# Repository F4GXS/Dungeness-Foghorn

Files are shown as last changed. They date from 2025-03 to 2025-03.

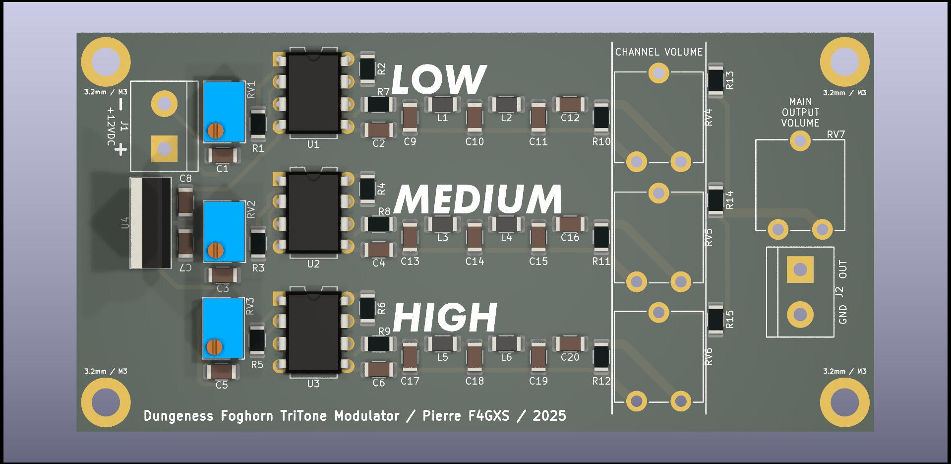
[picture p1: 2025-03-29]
FogHorn_PCB_1.jpg

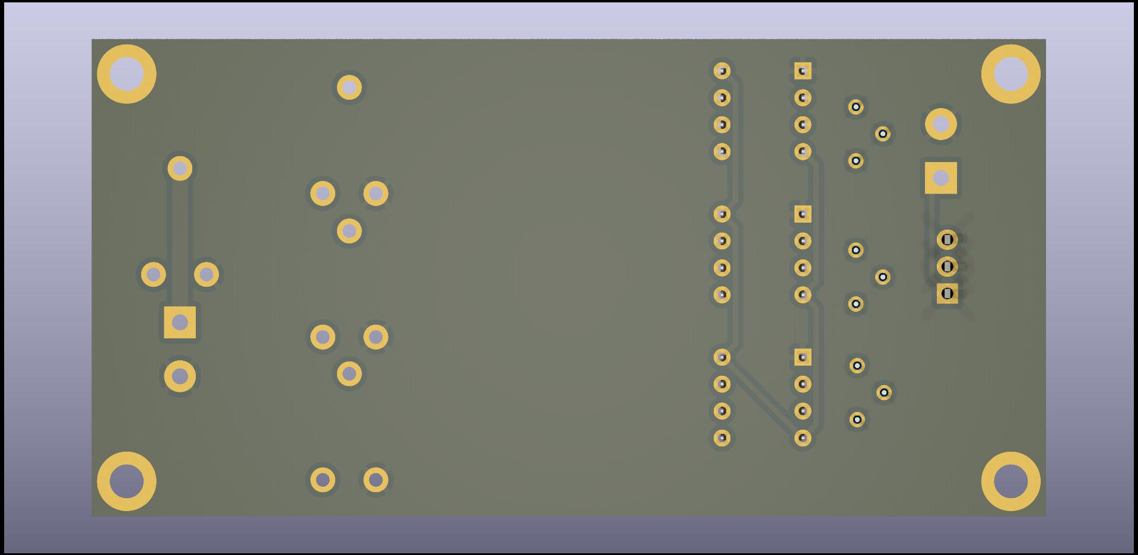
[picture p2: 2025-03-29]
FogHorn_PCB_2.jpg

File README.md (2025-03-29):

# Dungeness Lighthouse / St Ann's Lighthouse Foghorn Modulator
Tritone modulation of the famous Foghorn from the Dungeness Lighthouse #5 and the St Ann's Lighthouse.

The "Foghorn TriTone Modulator" is a very simple project I made to remind us of the famous and very specific tone of the foghorn.

mqdefault (https://www.youtube.com/watch?v=U48cCQ7XAnM)  
Click this image to hear the sound.  
_Source : YouTube -  St Anns Fog Signal / "Association of Lighthouse Keepers" Channel_

Dungeness_Lighthouse5
Dungeness_Lighthouse5_FogHornSPK (https://www.youtube.com/watch?v=Ncq_DsAXrBo)  
Click this image to hear the sound.  
_Source : YouTube -  Dungeness 5 fog horn: 26 minutes of Tannoy fog horn / "hellooldchap" Channel_

> In 1954-56, trials had been carried out at Dungeness of a triple-frequency electric fog signal, sounded through tannoy emitters built into a curved stack of precast concrete blocks. The experiment was deemed a success, and tannoy stacks were subsequently installed by Trinity House at around a dozen lighthouse stations. At Dungeness itself, a stack of sixty such emitters was incorporated into the design of the lighthouse tower itself; these remained in use until the year 2000, when they were replaced by an electronic signal installed at the base of the tower. It sounded three blasts every minute (altered in 2022 to one blast every 30 seconds).  
_Source : [Wikipedia](https://en.wikipedia.org/wiki/Dungeness_Lighthouse)_

## Electronic Schematic

FogHorn_Schema

This modulator is very simple, bases on 3 NE555 Timer IC for each tone, the NE555 can easily create square wave tone with few component for tuning and each NE555 have a 5 Order LowPass Filter to transform squares waveforms tones into sines waveforms tone.

The power input voltage are 12VDC equiped with a LM7805 5VDC for the NE555.

Each channel have a multiturn potentiometer for precision frequency tuning.

The modulator are equiped with a passive inboard mixer, 3 potentiometer (1 pot for each channel, regulate the volume of each tone) and 1 for the main volume to regulate the main mix.

## Printed Circuit Board

FogHorn_PCB_1

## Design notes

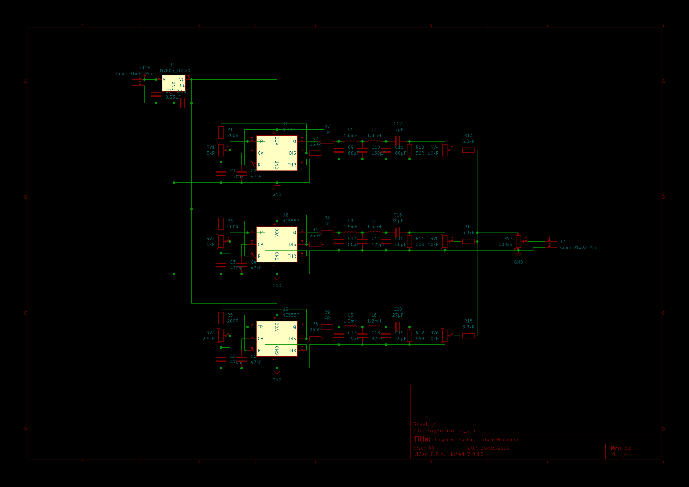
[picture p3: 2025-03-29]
FogHorn_Schema.jpg

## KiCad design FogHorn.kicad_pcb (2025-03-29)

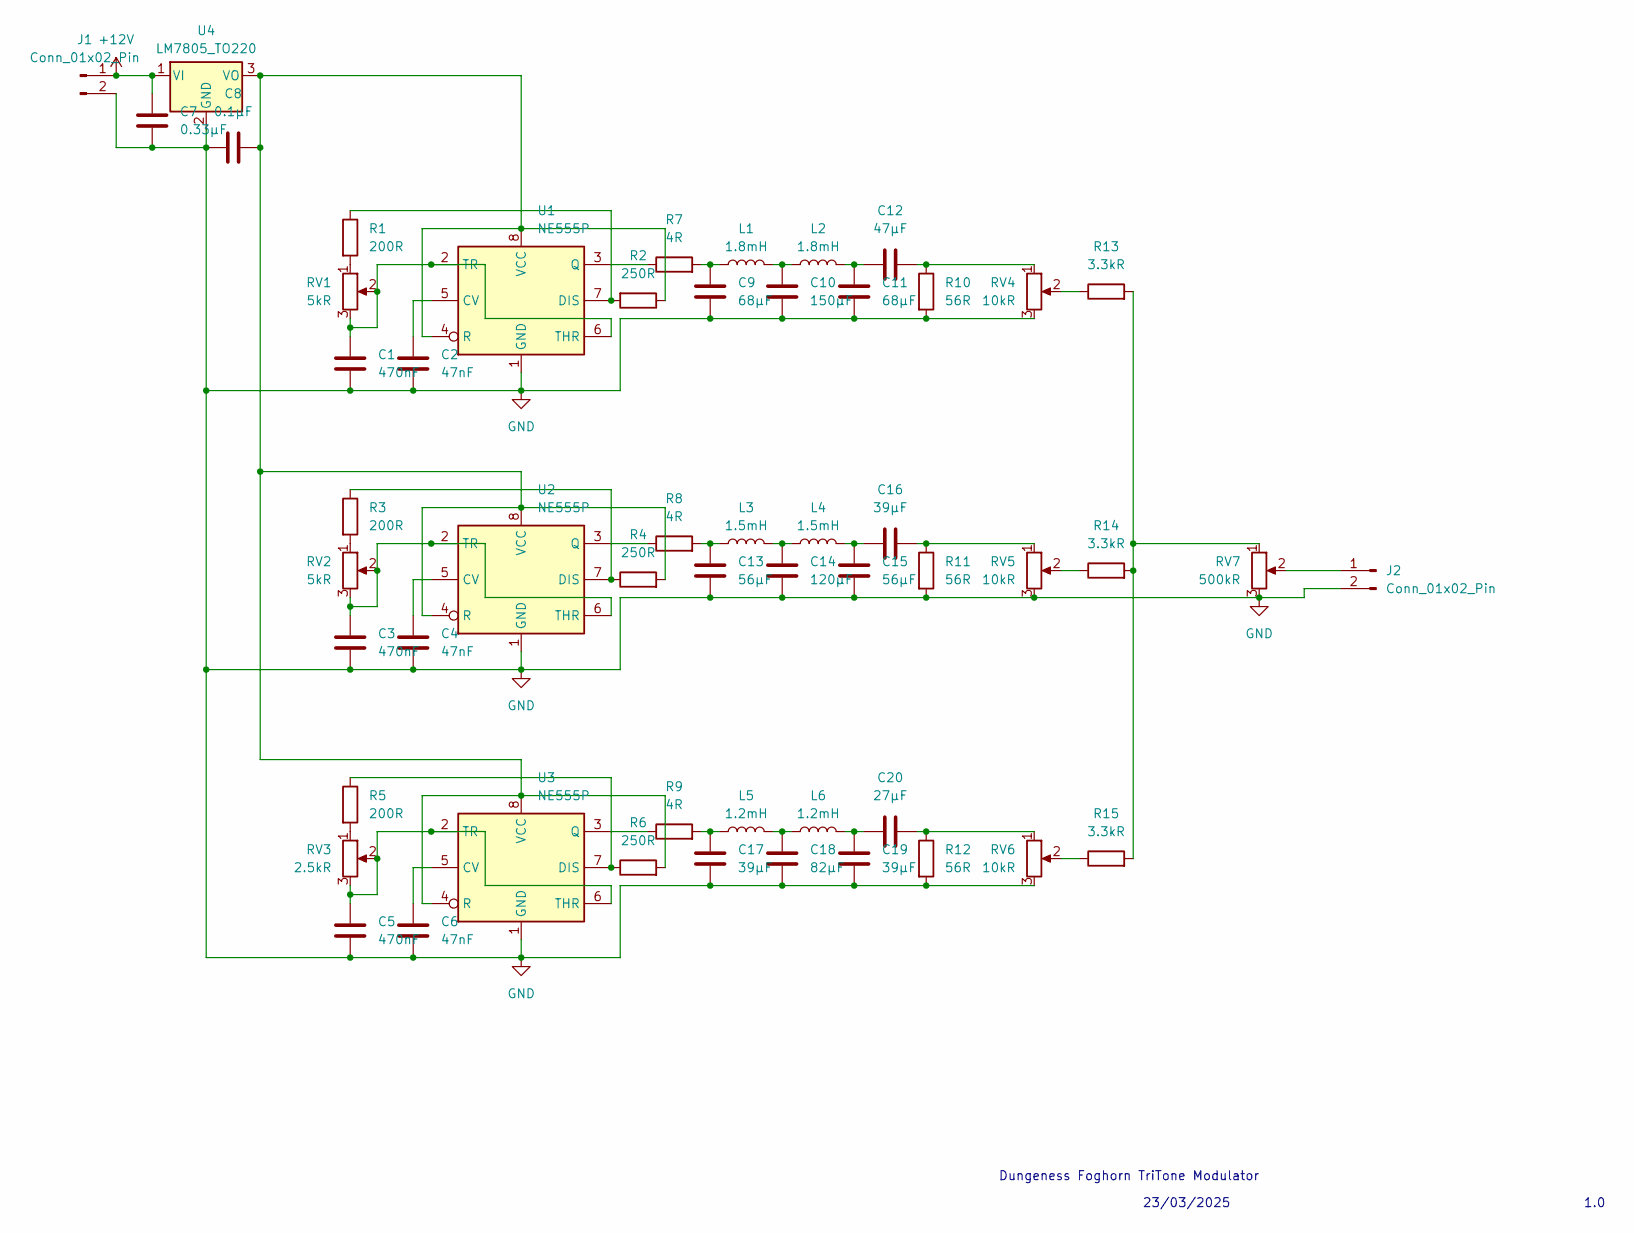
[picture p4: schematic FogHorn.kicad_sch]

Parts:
C1, C3, C5: 470nF; C_1206_3216Metric
C2, C4, C6: 47nF; C_1206_3216Metric
C7: 0.33µF; C_1206_3216Metric
C8: 0.1µF; C_1206_3216Metric
C9, C11: 68µF; C_1206_3216Metric
C10: 150µF; C_1206_3216Metric
C12: 47µF; C_1206_3216Metric
C13, C15: 56µF; C_1206_3216Metric
C14: 120µF; C_1206_3216Metric
C16, C17, C19: 39µF; C_1206_3216Metric
C18: 82µF; C_1206_3216Metric
C20: 27µF; C_1206_3216Metric
J1, J2: Conn_01x02_Pin; TerminalBlock_bornier-2_P5.08mm
L1, L2: 1.8mH; L_1206_3216Metric
L3, L4: 1.5mH; L_1206_3216Metric
L5, L6: 1.2mH; L_1206_3216Metric
R1, R3, R5: 200R; R_1206_3216Metric
R2, R4, R6: 250R; R_1206_3216Metric
R7, R8, R9: 4R; R_1206_3216Metric
R10, R11, R12: 56R; R_1206_3216Metric
R13, R14, R15: 3.3kR; R_1206_3216Metric
RV1, RV2: 5kR; Potentiometer_Bourns_3266W_Vertical
RV3: 2.5kR; Potentiometer_Bourns_3266W_Vertical
RV4, RV5, RV6: 10kR; Potentiometer_ACP_CA9-V10_Vertical
RV7: 500kR; Potentiometer_ACP_CA9-V10_Vertical
U1, U2, U3: NE555P; DIP-8_W7.62mm
U4: LM7805_TO220; TO-220-3_Vertical

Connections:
+12V: C7.1, J1.1, U4.1 (VI)
GND: C1.2, C2.2, C3.2, C4.2, C5.2, C6.2, C7.2, C8.1, C9.2, C10.2, C11.2, C13.2, C14.2, C15.2, C17.2, C18.2, C19.2, J1.2, J2.2, R10.2, R11.2, R12.2, RV4.3, RV5.3, RV6.3, RV7.3, U1.1 (GND), U2.1 (GND), U3.1 (GND), U4.2 (GND)
unnamed: C9.1, L1.1, R7.2
unnamed: C10.1, L1.2, L2.1
unnamed: C11.1, C12.1, L2.2
unnamed: C12.2, R10.1, RV4.1
unnamed: C13.1, L3.1, R8.2
unnamed: C14.1, L3.2, L4.1
unnamed: C15.1, C16.1, L4.2
unnamed: C16.2, R11.1, RV5.1
unnamed: C17.1, L5.1, R9.2
unnamed: C18.1, L5.2, L6.1
unnamed: C19.1, C20.1, L6.2
unnamed: C20.2, R12.1, RV6.1
unnamed: J2.1, RV7.2
unnamed: R1.2, RV1.1
unnamed: R3.2, RV2.1
unnamed: R5.2, RV3.1
unnamed: R13.1, RV4.2
unnamed: R13.2, R14.2, R15.2, RV7.1
unnamed: R14.1, RV5.2
unnamed: R15.1, RV6.2
unnamed: C2.1, U1.5 (CV)
unnamed: R1.1, R2.2, U1.7 (DIS)
unnamed: R7.1, U1.3 (Q)
unnamed: C8.2, R2.1, R4.2, R6.2, U1.4 (R), U1.8 (VCC), U2.4 (R), U2.8 (VCC), U3.4 (R), U3.8 (VCC), U4.3 (VO)
unnamed: C1.1, RV1.2, RV1.3, U1.2 (TR), U1.6 (THR)
unnamed: C4.1, U2.5 (CV)
unnamed: R3.1, R4.1, U2.7 (DIS)
unnamed: R8.1, U2.3 (Q)
unnamed: C3.1, RV2.2, RV2.3, U2.2 (TR), U2.6 (THR)
unnamed: C6.1, U3.5 (CV)
unnamed: R5.1, R6.1, U3.7 (DIS)
unnamed: R9.1, U3.3 (Q)
unnamed: C5.1, RV3.2, RV3.3, U3.2 (TR), U3.6 (THR)

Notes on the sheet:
Dungeness Foghorn TriTone Modulator
1.0
23/03/2025

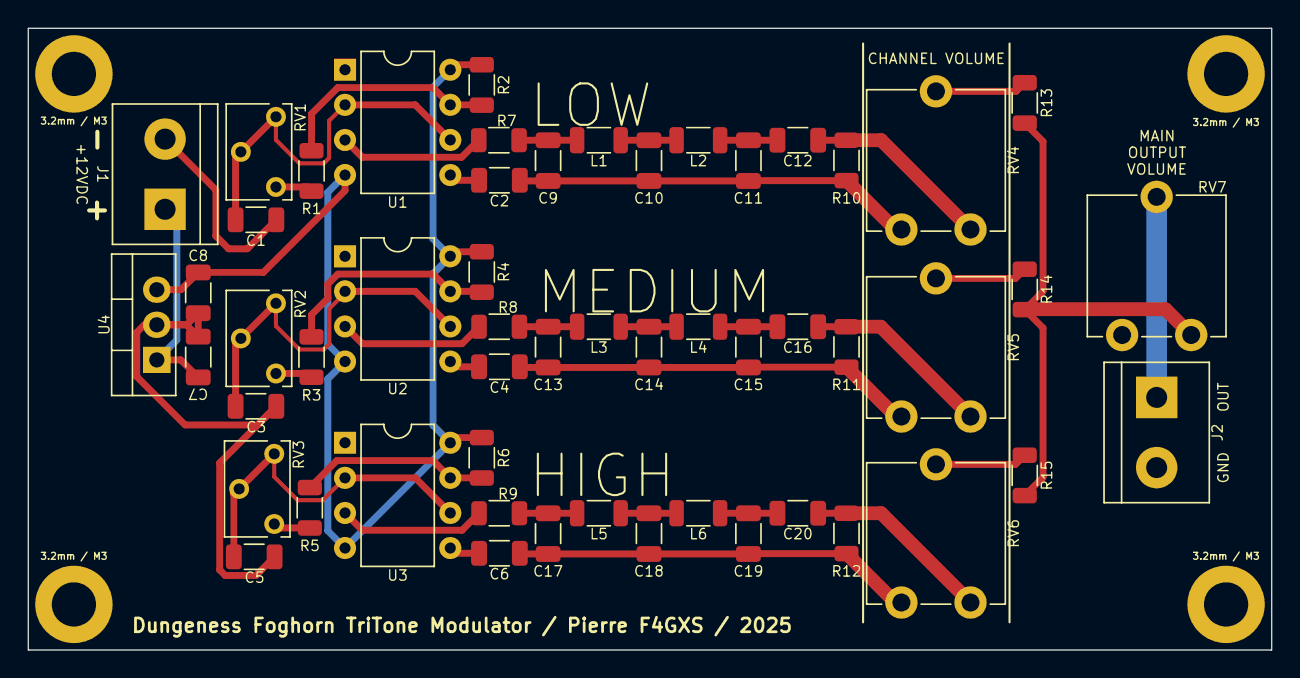
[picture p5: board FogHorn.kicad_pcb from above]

Board: 2 copper layers, 90.0 x 45.0 mm, 58 parts (0 on the bottom side), 35 nets.

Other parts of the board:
3.2mm / M3, 3.2mm / M3#2, 3.2mm / M3#3, 3.2mm / M3#4: MountingHole_3.2mm_M3_DIN965_Pad
